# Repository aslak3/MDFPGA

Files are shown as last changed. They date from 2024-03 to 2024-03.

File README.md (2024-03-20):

# MDFPGA: a HUB75 display controller base board using a Pi Pico W and an iCE40UP5K

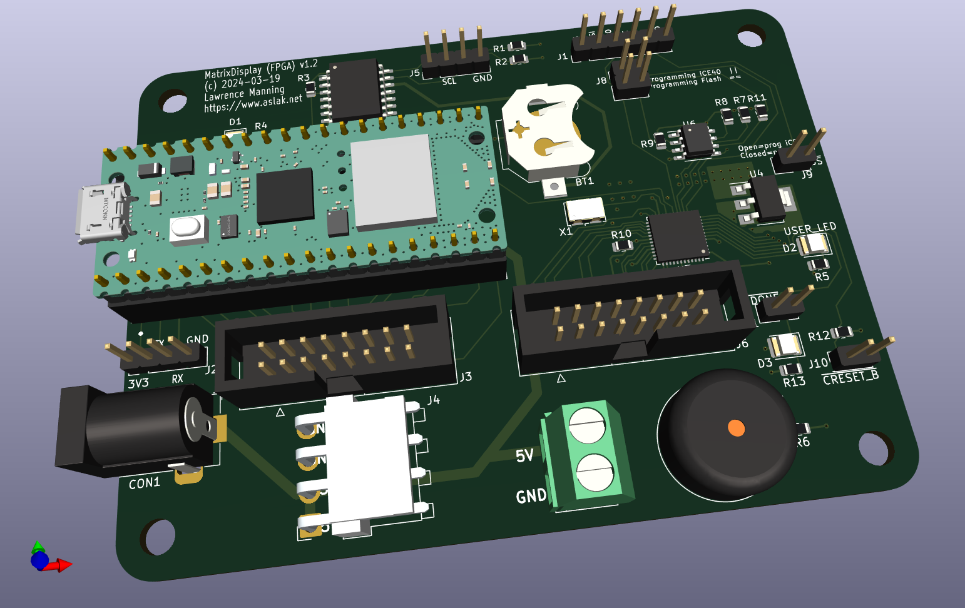
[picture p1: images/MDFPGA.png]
MDFPGA PCB


A [schematic](MDFPGA.pdf) is included here, along with the [KiCAD](https://www.kicad.org)
data files, which are in KiCAD 6 format.

## PCB design

The PCB is a 4 layer board easily built by any random PCB house.

## Project overview

This board is the hardware for my Matrix Display project, which is spread across three repos: this one, [a repo holding the Pico W firmware](https://github.com/aslak3/matrix-display), and [an optional one that holds the HUB75 display controller](https://github.com/aslak3/hub75-controller), which is implemented in Verilog.

Once up and running, you will have a 64 x 32 LED matrix display, presenting information from your Home Assistant system or, in theory, any other system that publish data in a suitable format via MQTT.

## Hardware description

* Power via 5V barrel jack
* A Pi Pico W (obviously)
* A [DS3231](https://www.analog.com/media/en/technical-documentation/data-sheets/DS3231.pdf) (PDF) I2C Real Time Clock
  * CR122t battery backup
* IDC16 HUB75 connector attached to the Pico W
* Buzzer
* iCE40UP FPGA
  * [N25Q32A](https://www.mouser.co.uk/datasheet/2/12/Micron_Datasheet_N25Q032A_RevJ-1880047.pdf) (PDF) 32MBit SPI Flash
  * IDC16 HUB75 connector attached to the FPGA
  * LED

## Possible gotchas

The board revision included here fixes some minor issues I found in the board I use on a daily basis:

* The CR1225 conenctor has been moved a few mm to make it easier to insert and remove the battery.
* The screw terminals, which power the HUB75 panel, have been pointed in the oposite direction, making them easier to access.
* More vias have been added around the 1.2V power pin on the linear regulator.

## References

* [Matrix Display](https://github.com/aslak3/matrix-display) The projects main repository. which holds the firmware source code.
* [HUB75 Controller](https://github.com/aslak3/hub75-controller) A HUB75 LED matrix controller implemented in Verilog.

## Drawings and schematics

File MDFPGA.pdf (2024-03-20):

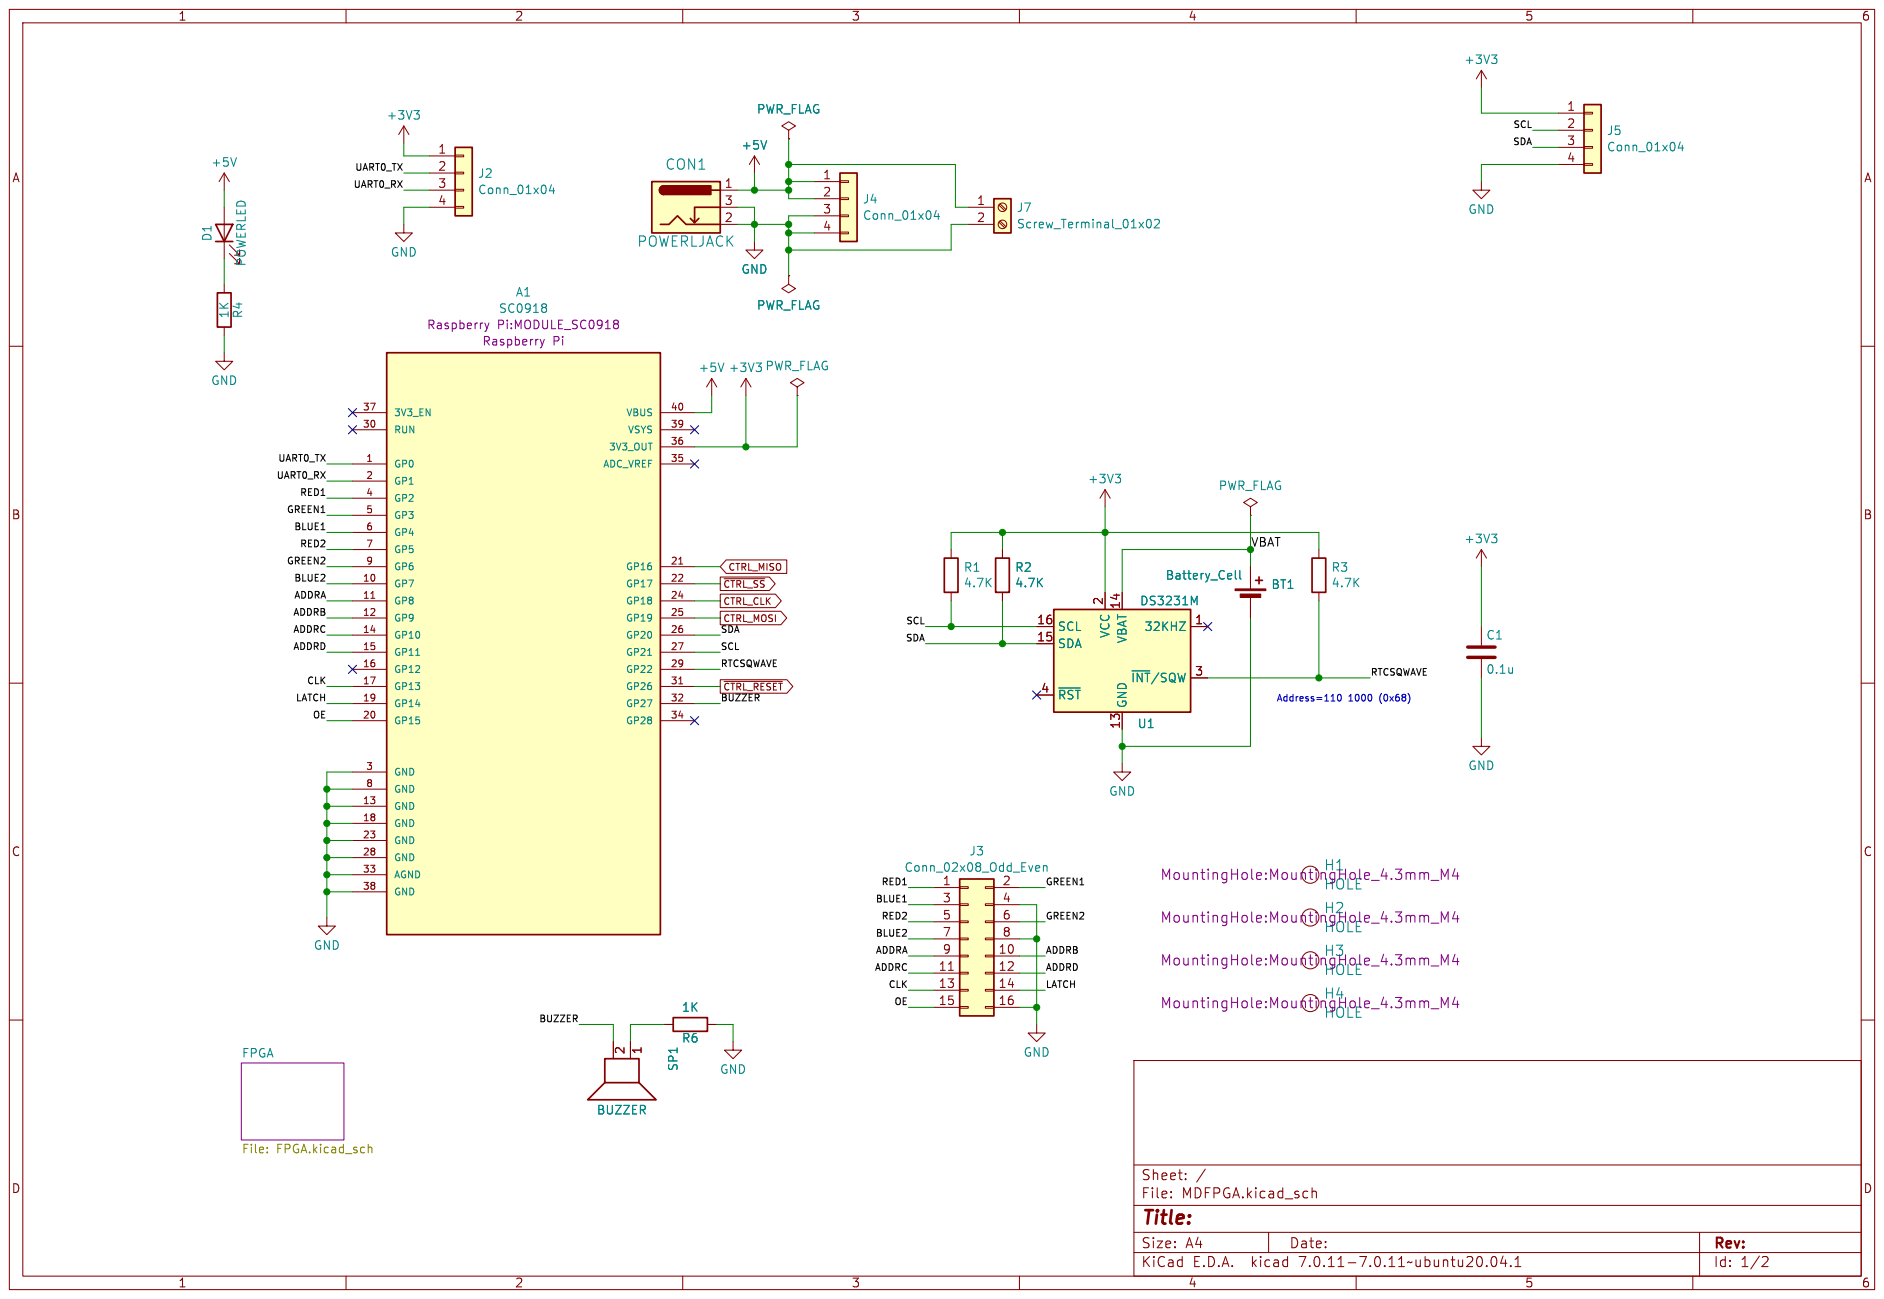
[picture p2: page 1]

Id: 1/2 Title: File: MDFPGA.kicad_sch Sheet: / FPGA

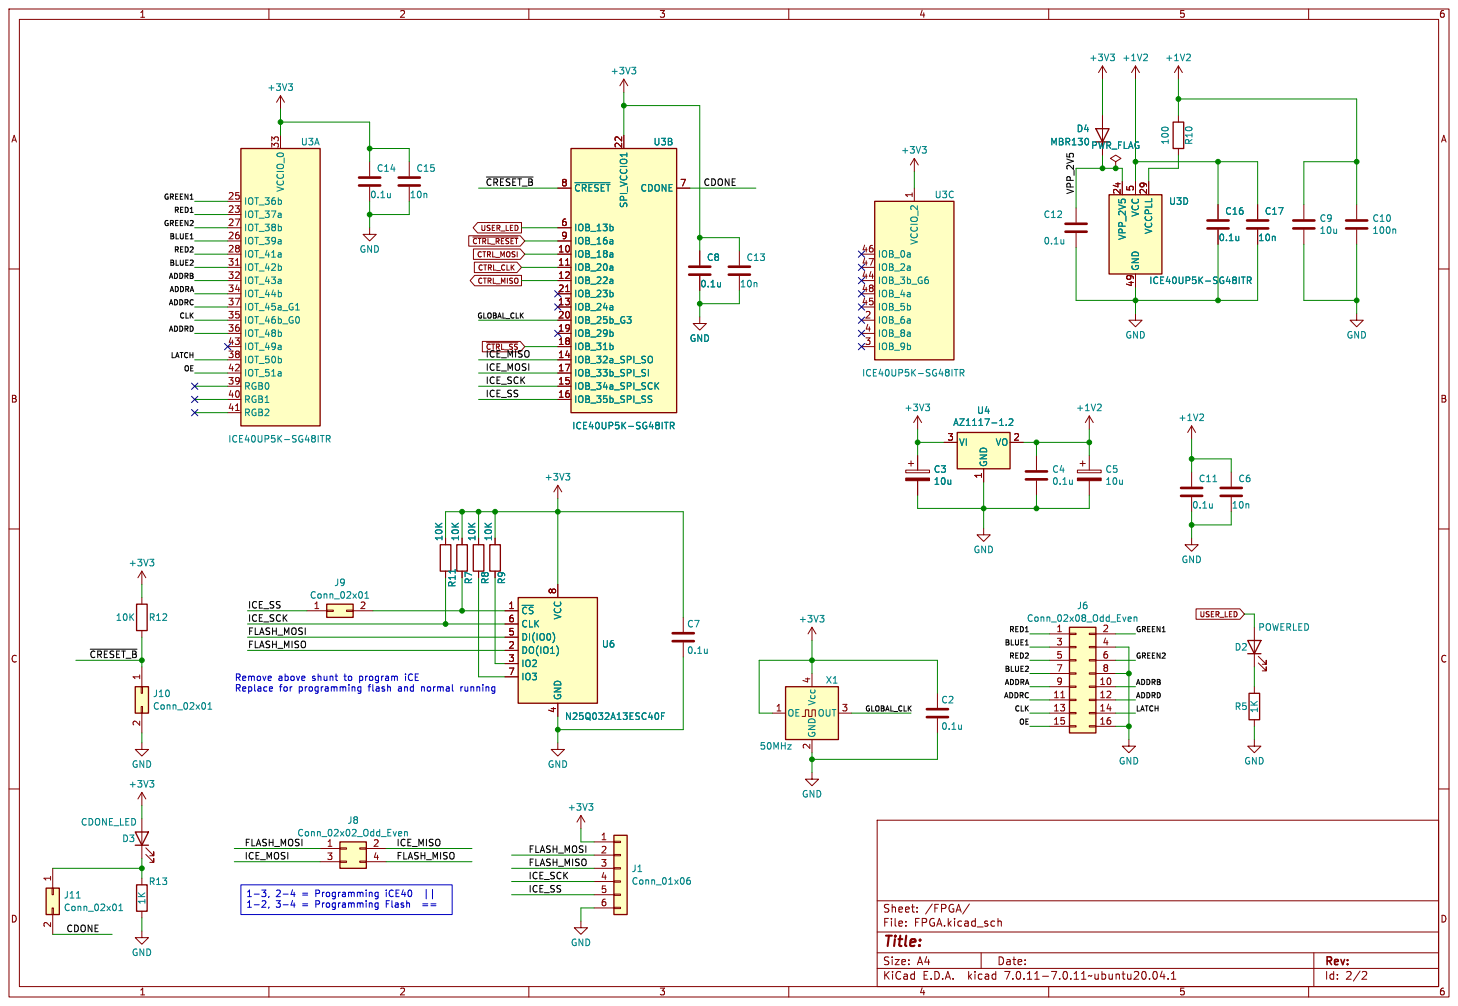
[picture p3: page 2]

Id: 2/2 Title: File: FPGA.kicad_sch Sheet: /FPGA/ R13 1K

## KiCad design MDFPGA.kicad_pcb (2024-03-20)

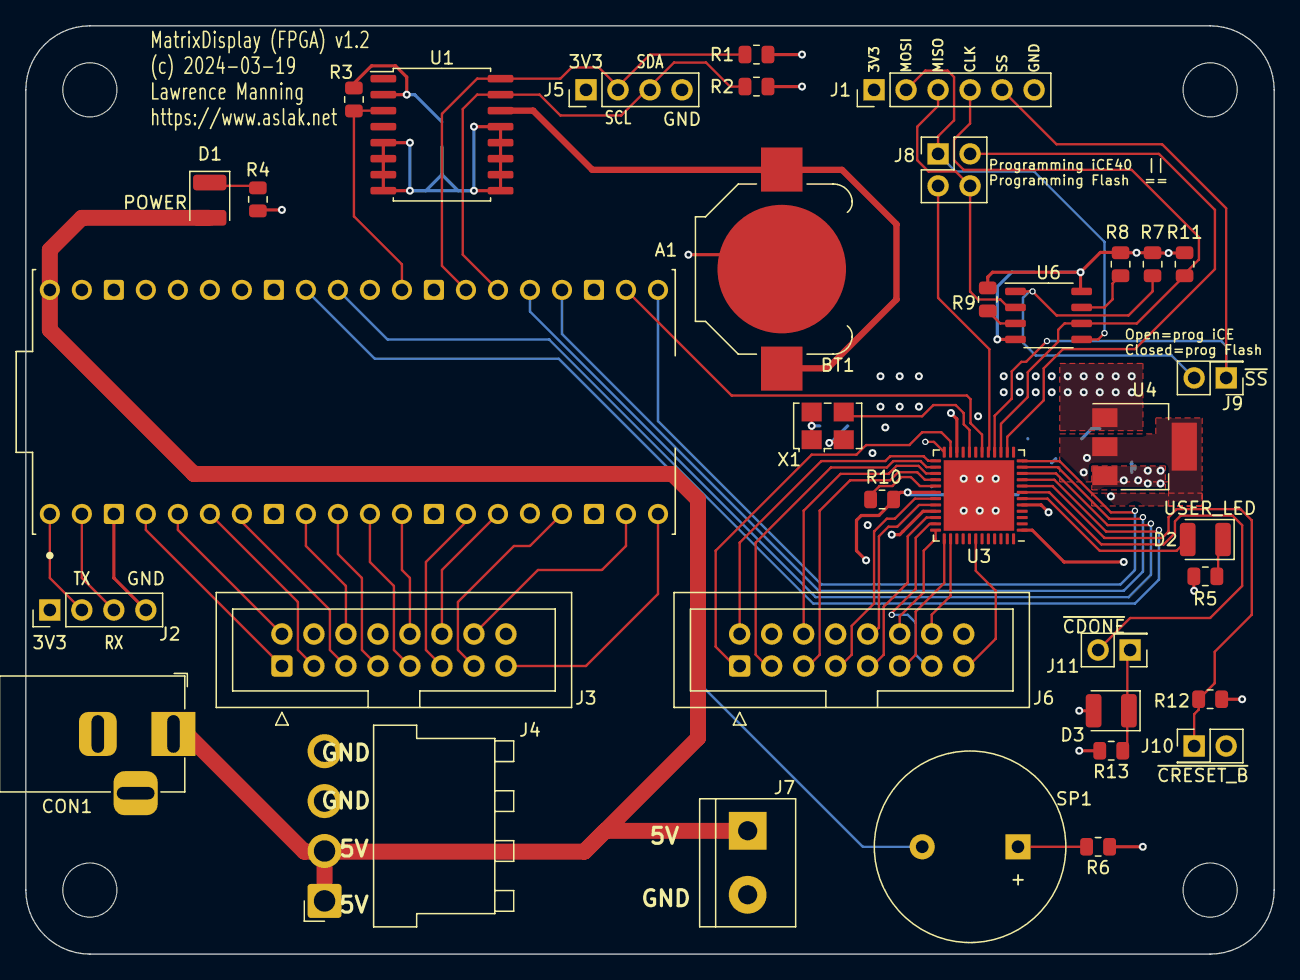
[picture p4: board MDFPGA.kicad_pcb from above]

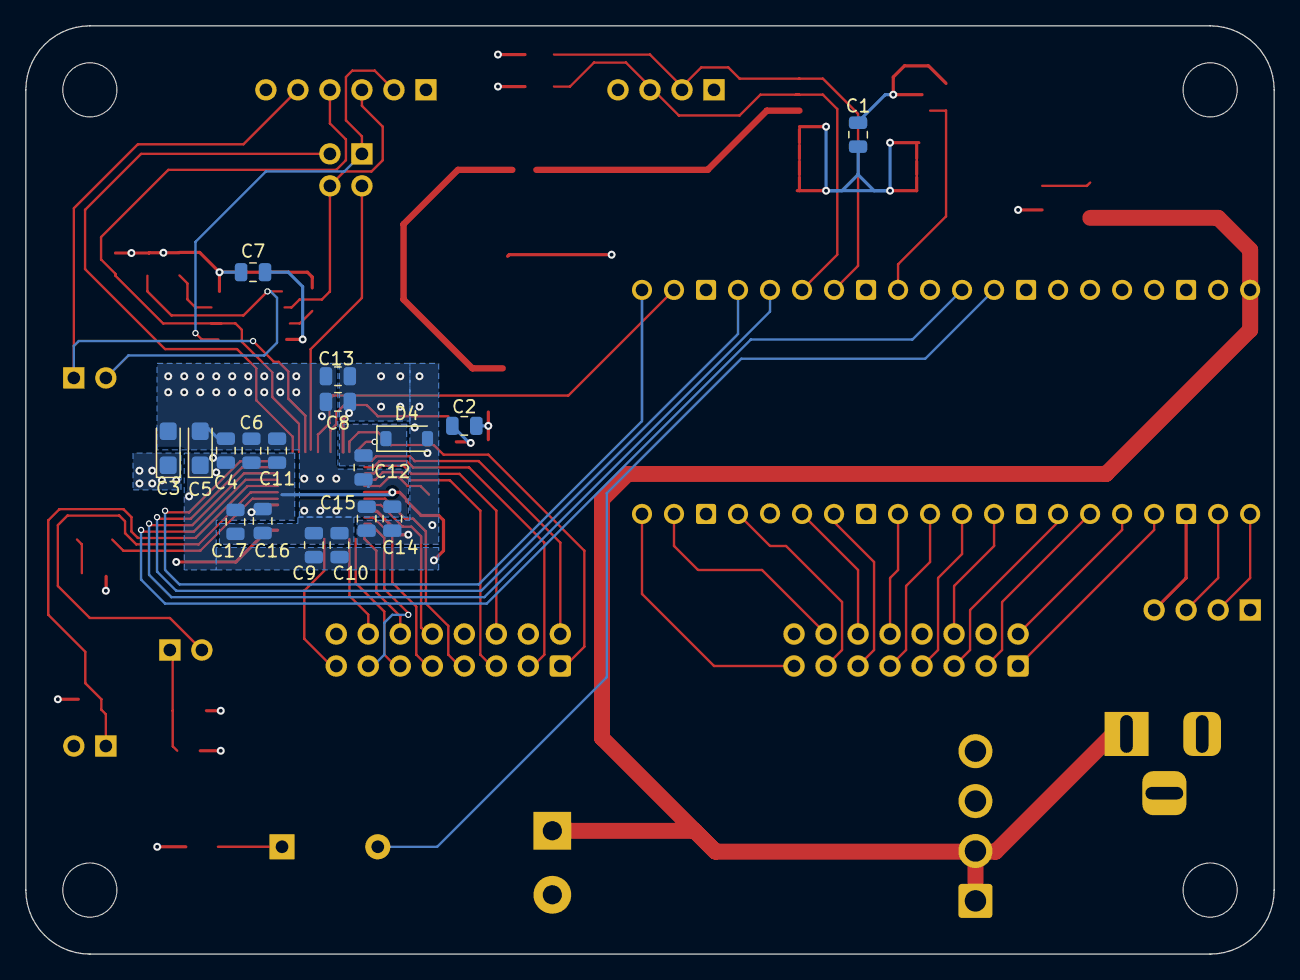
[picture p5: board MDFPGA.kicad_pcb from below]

Board: 4 copper layers, 99.1 x 73.7 mm, 58 parts (18 on the bottom side), 61 nets.

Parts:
A1: SC0918; MODULE_SC0918
BT1: Battery_Cell; BatteryHolder_Keystone_3000_1x12mm
C1, C2, C4, C7, C8, C11, C12, C14, C16: 0.1u; C_0805_2012Metric
C3, C5: 10u; CP_EIA-3216-10_Kemet-I
C6, C13, C15, C17: 10n; C_0805_2012Metric
C9: 10u; C_0805_2012Metric
C10: 100n; C_0805_2012Metric
CON1: POWERLJACK; BarrelJack_Horizontal
D1, D2: POWERLED; LED_1210_3225Metric
D3: CDONE_LED; LED_1210_3225Metric
D4: MBR130; D_SOD-123
H1, H2, H3, H4: HOLE; MountingHole_4.3mm_M4
J1: Conn_01x06; PinHeader_1x06_P2.54mm_Vertical
J2, J5: Conn_01x04; PinHeader_1x04_P2.54mm_Vertical
J3, J6: Conn_02x08_Odd_Even; IDC-Header_2x08_P2.54mm_Vertical
J4: Conn_01x04; JST_VH_B4PS-VH_1x04_P3.96mm_Horizontal
J7: Screw_Terminal_01x02; TerminalBlock_bornier-2_P5.08mm
J8: Conn_02x02_Odd_Even; PinHeader_2x02_P2.54mm_Vertical
J9, J10, J11: Conn_02x01; PinHeader_2x01_P2.54mm_Vertical
R1, R2, R3: 4.7K; R_0805_2012Metric
R4, R5, R6, R13: 1K; R_0805_2012Metric
R7, R8, R9, R11, R12: 10K; R_0805_2012Metric
R10: 100; R_0805_2012Metric
SP1: BUZZER; Buzzer_15x7.5RM7.6
U1: DS3231M; SOIC-16W_7.5x10.3mm_P1.27mm
U3: ICE40UP5K-SG48ITR; QFN-48-1EP_7x7mm_P0.5mm_EP5.6x5.6mm
U4: AZ1117-1.2; SOT-223-3_TabPin2
U6: N25Q032A13ESC40F; SOP-8_3.9x4.9mm_P1.27mm
X1: 50MHz; Oscillator_SMD_SeikoEpson_SG8002LB-4Pin_5.0x3.2mm

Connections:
+1V2: C4.1, C5.1, C6.1, C9.1, C10.1, C11.1, C16.1, C17.1, R10.1, U3.5 (VCC), U3.30 (VCC), U4.2 (VO)
+3V3: A1.36 (3V3_OUT), C1.1, C2.1, C3.1, C7.1, C8.1, C13.1, C14.1, C15.1, D3.2 (A), D4.2 (A), J1.1, J2.1, J5.1, R1.1, R2.1, R3.1, R7.1, R8.1, R9.1, R11.1, R12.1, U1.2 (VCC), U3.1 (VCCIO_2), U3.22 (SPI_VCCIO1), U3.33 (VCCIO_0), U4.3 (VI), U6.8 (VCC), X1.1 (OE), X1.4 (Vcc)
+5V: A1.40 (VBUS), CON1.1, D1.2 (A), J4.1, J4.2, J7.1
/ADDRA: A1.11 (GP8), J3.9
/ADDRB: A1.12 (GP9), J3.10
/ADDRC: A1.14 (GP10), J3.11
/ADDRD: A1.15 (GP11), J3.12
/BLUE1: A1.6 (GP4), J3.3
/BLUE2: A1.10 (GP7), J3.7
/BUZZER: A1.32 (GP27), SP1.2
/CLK: A1.17 (GP13), J3.13
/FPGA/ADDRA: J6.9, U3.34 (IOT_44b)
/FPGA/ADDRB: J6.10, U3.32 (IOT_43a)
/FPGA/ADDRC: J6.11, U3.37 (IOT_45a_G1)
/FPGA/ADDRD: J6.12, U3.36 (IOT_48b)
/FPGA/BLUE1: J6.3, U3.26 (IOT_39a)
/FPGA/BLUE2: J6.7, U3.31 (IOT_42b)
/FPGA/CDONE: J11.2, U3.7 (CDONE)
/FPGA/CLK: J6.13, U3.35 (IOT_46b_G0)
/FPGA/FLASH_MISO: J1.3, J8.4, U6.2 (DO(IO1))
/FPGA/FLASH_MOSI: J1.2, J8.1, U6.5 (DI(IO0))
/FPGA/GLOBAL_CLK: U3.20 (IOB_25b_G3), X1.3 (OUT)
/FPGA/GREEN1: J6.2, U3.25 (IOT_36b)
/FPGA/GREEN2: J6.6, U3.27 (IOT_38b)
/FPGA/ICE_MISO: J8.2, U3.14 (IOB_32a_SPI_SO)
/FPGA/ICE_MOSI: J8.3, U3.17 (IOB_33b_SPI_SI)
/FPGA/ICE_SCK: J1.4, R11.2, U3.15 (IOB_34a_SPI_SCK), U6.6 (CLK)
/FPGA/ICE_SS: J1.5, J9.1, U3.16 (IOB_35b_SPI_SS)
/FPGA/LATCH: J6.14, U3.38 (IOT_50b)
/FPGA/OE: J6.15, U3.42 (IOT_51a)
/FPGA/RED1: J6.1, U3.23 (IOT_37a)
/FPGA/RED2: J6.5, U3.28 (IOT_41a)
/FPGA/VPP_2V5: C12.1, D4.1 (K), U3.24 (VPP_2V5)
/FPGA/~CRESET_B: J10.1, R12.2, U3.8 (~CRESET)
/GREEN1: A1.5 (GP3), J3.2
/GREEN2: A1.9 (GP6), J3.6
/LATCH: A1.19 (GP14), J3.14
/OE: A1.20 (GP15), J3.15
/RED1: A1.4 (GP2), J3.1
/RED2: A1.7 (GP5), J3.5
/RTCSQWAVE: A1.29 (GP22), R3.2, U1.3 (~INT/SQW)
/SCL: A1.27 (GP21), J5.2, R1.2, U1.16 (SCL)
/SDA: A1.26 (GP20), J5.3, R2.2, U1.15 (SDA)
/UART0_RX: A1.2 (GP1), J2.3
/UART0_TX: A1.1 (GP0), J2.2
/VBAT: BT1.1 (+), U1.14 (VBAT)
CTRL_CLK: A1.24 (GP18), U3.11 (IOB_20a)
CTRL_MISO: A1.21 (GP16), U3.12 (IOB_22a)
CTRL_MOSI: A1.25 (GP19), U3.10 (IOB_18a)
GND: A1.3 (GND), A1.8 (GND), A1.13 (GND), A1.18 (GND), A1.23 (GND), A1.28 (GND), A1.33 (AGND), A1.38 (GND), BT1.2 (-), C1.2, C2.2, C3.2, C4.2, C5.2, C6.2, C7.2, C8.2, C9.2, C10.2, C11.2, C12.2, C13.2, C14.2, C15.2, C16.2, C17.2, CON1.2, CON1.3, J1.6, J2.4, J3.4, J3.8, J3.16, J4.3, J4.4, J5.4, J6.4, J6.8, J6.16, J7.2, J10.2, R4.2, R5.2, R6.1, R13.2, U1.5 (GND), U1.6 (GND), U1.7 (GND), U1.8 (GND), U1.9 (GND), U1.10 (GND), U1.11 (GND), U1.12 (GND), U1.13 (GND), U3.49 (GND), U4.1 (GND), U6.4 (GND), X1.2 (GND)
unnamed: D1.1 (K), R4.1
unnamed: D2.1 (K), R5.1
unnamed: D3.1 (K), J11.1, R13.1
unnamed: J9.2, R7.2, U6.1 (~CS)
unnamed: R6.2, SP1.1
unnamed: R10.2, U3.29 (VCCPLL)
unnamed: R9.2, U6.3 (IO2)
unnamed: R8.2, U6.7 (IO3)
USER_LED: D2.2 (A), U3.6 (IOB_13b)
~CTRL_RESET: A1.31 (GP26), U3.9 (IOB_16a)
~CTRL_SS: A1.22 (GP17), U3.18 (IOB_31b)

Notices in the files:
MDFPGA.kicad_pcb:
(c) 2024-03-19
